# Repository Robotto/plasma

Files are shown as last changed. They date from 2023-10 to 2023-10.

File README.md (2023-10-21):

Interfacing a plasma VU meter from the past with an ESP8266 on a Wemos D1 mini board.

This is highly experimental, dangerous, and possibly fun.

[Interactive BOM here](https://htmlpreview.github.io/?https://github.com/robotto/plasma/blob/master/bom/ibom.html).

[OH! And check out KiCanvas!](https://kicanvas.org/?github=https%3A%2F%2Fgithub.com%2FRobotto%2Fplasma)

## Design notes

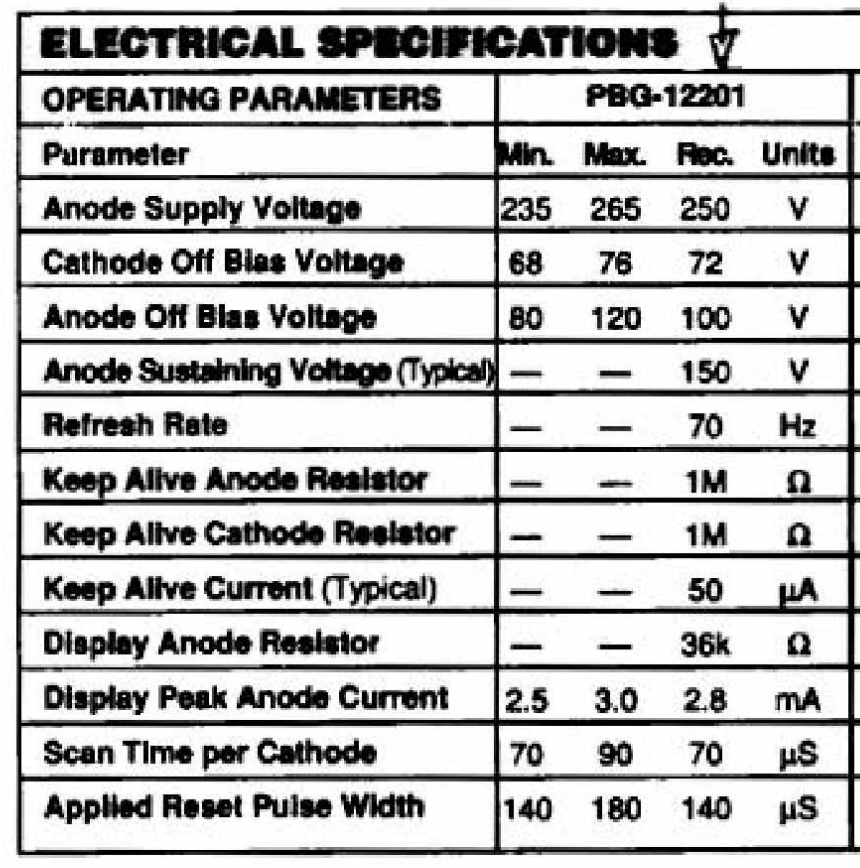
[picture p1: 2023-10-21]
electrical_specs.png

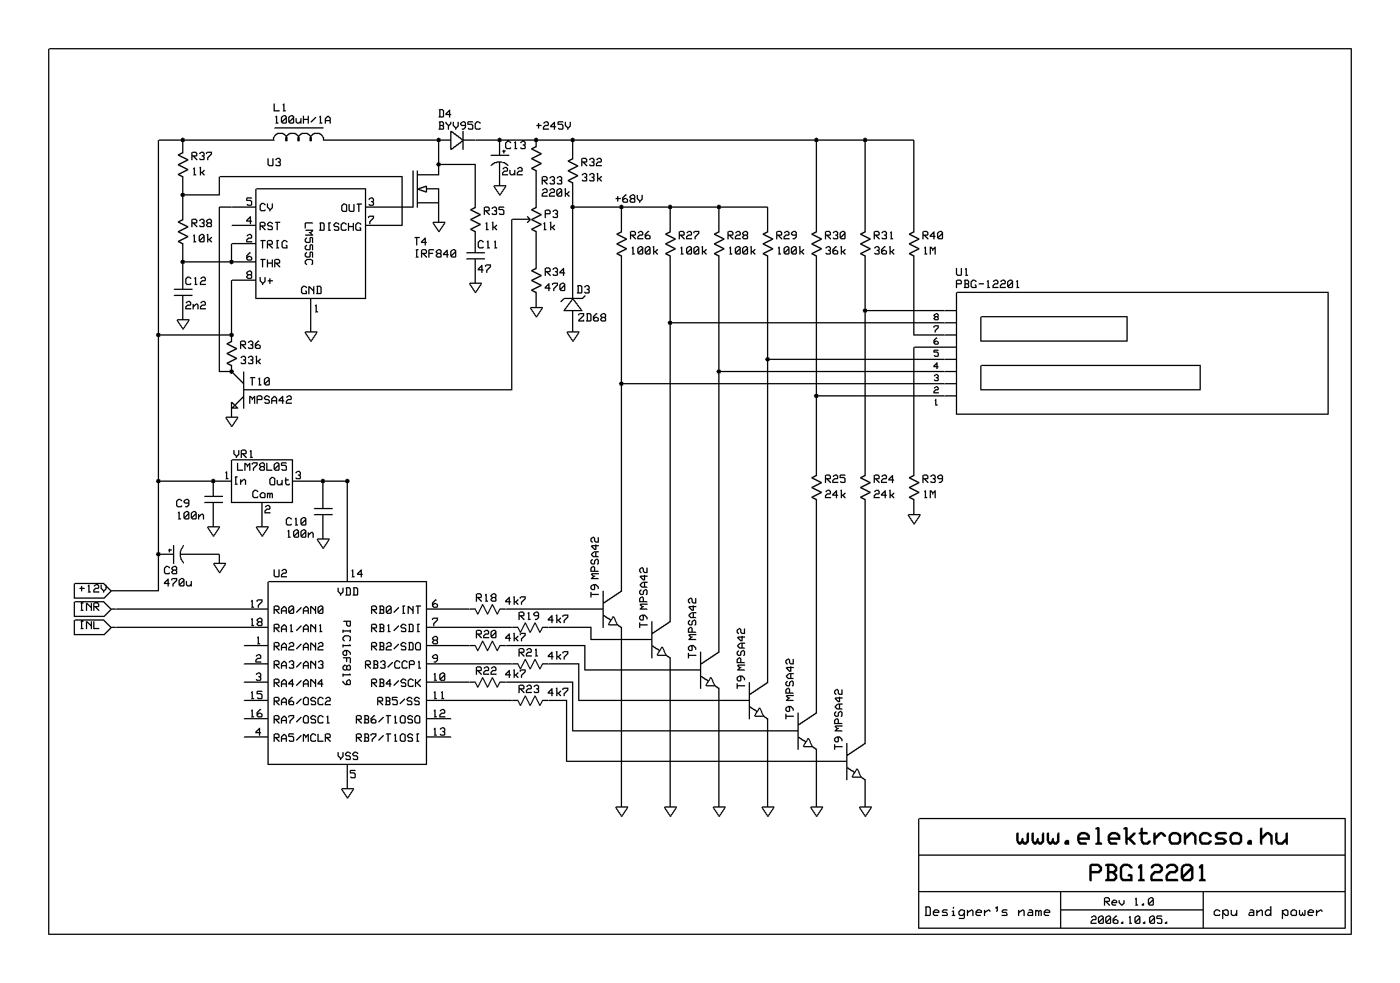
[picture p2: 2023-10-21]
plasma_VU_selfscan_kapcs.gif

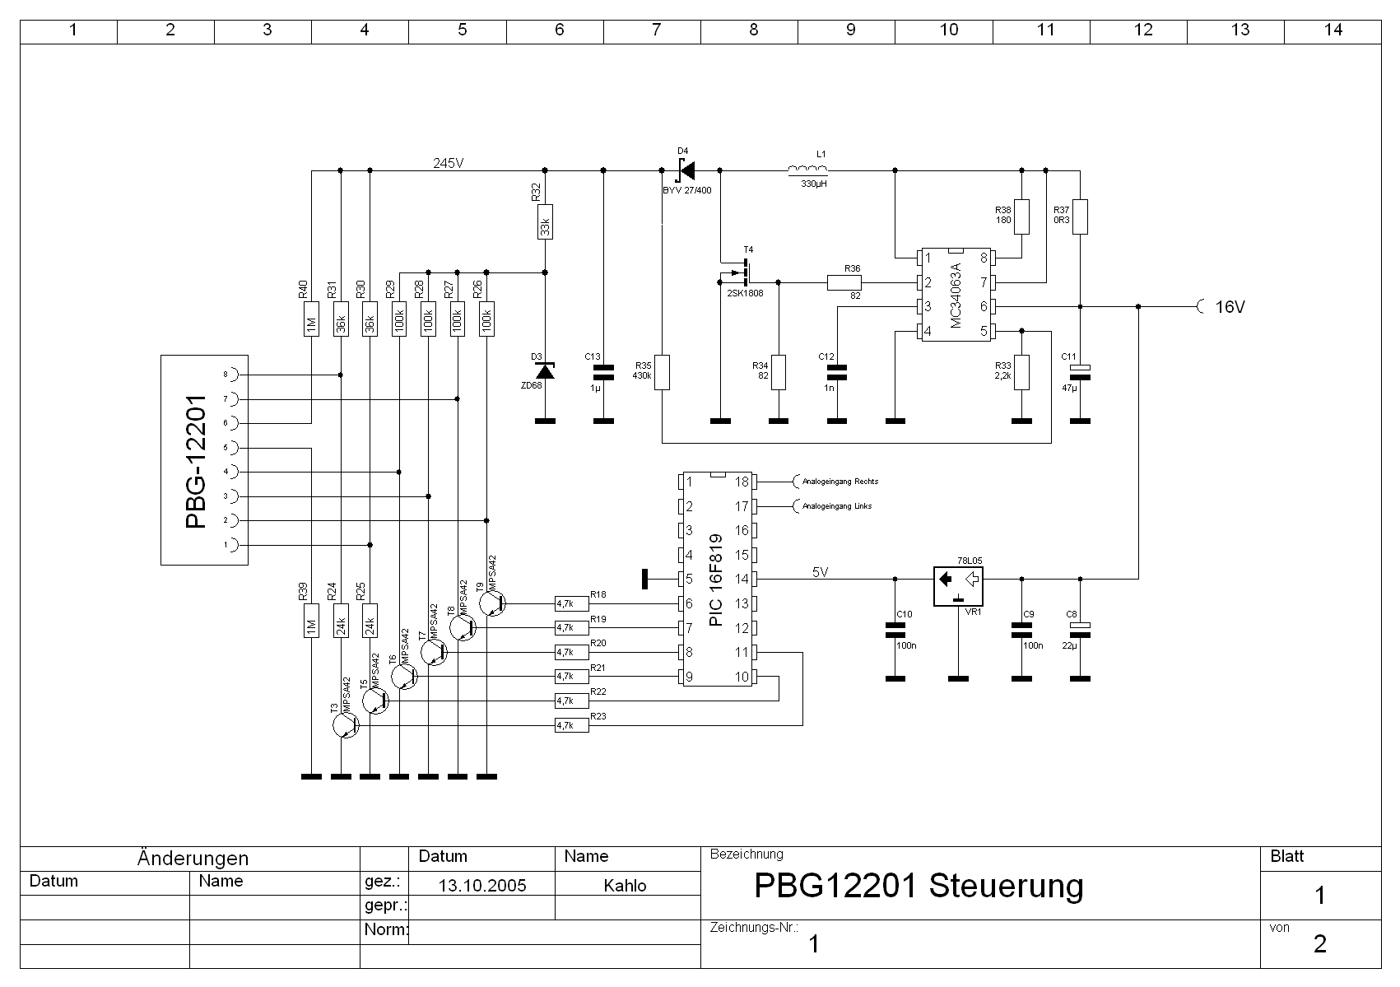
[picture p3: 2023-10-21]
Schaltplan_Teil1.gif

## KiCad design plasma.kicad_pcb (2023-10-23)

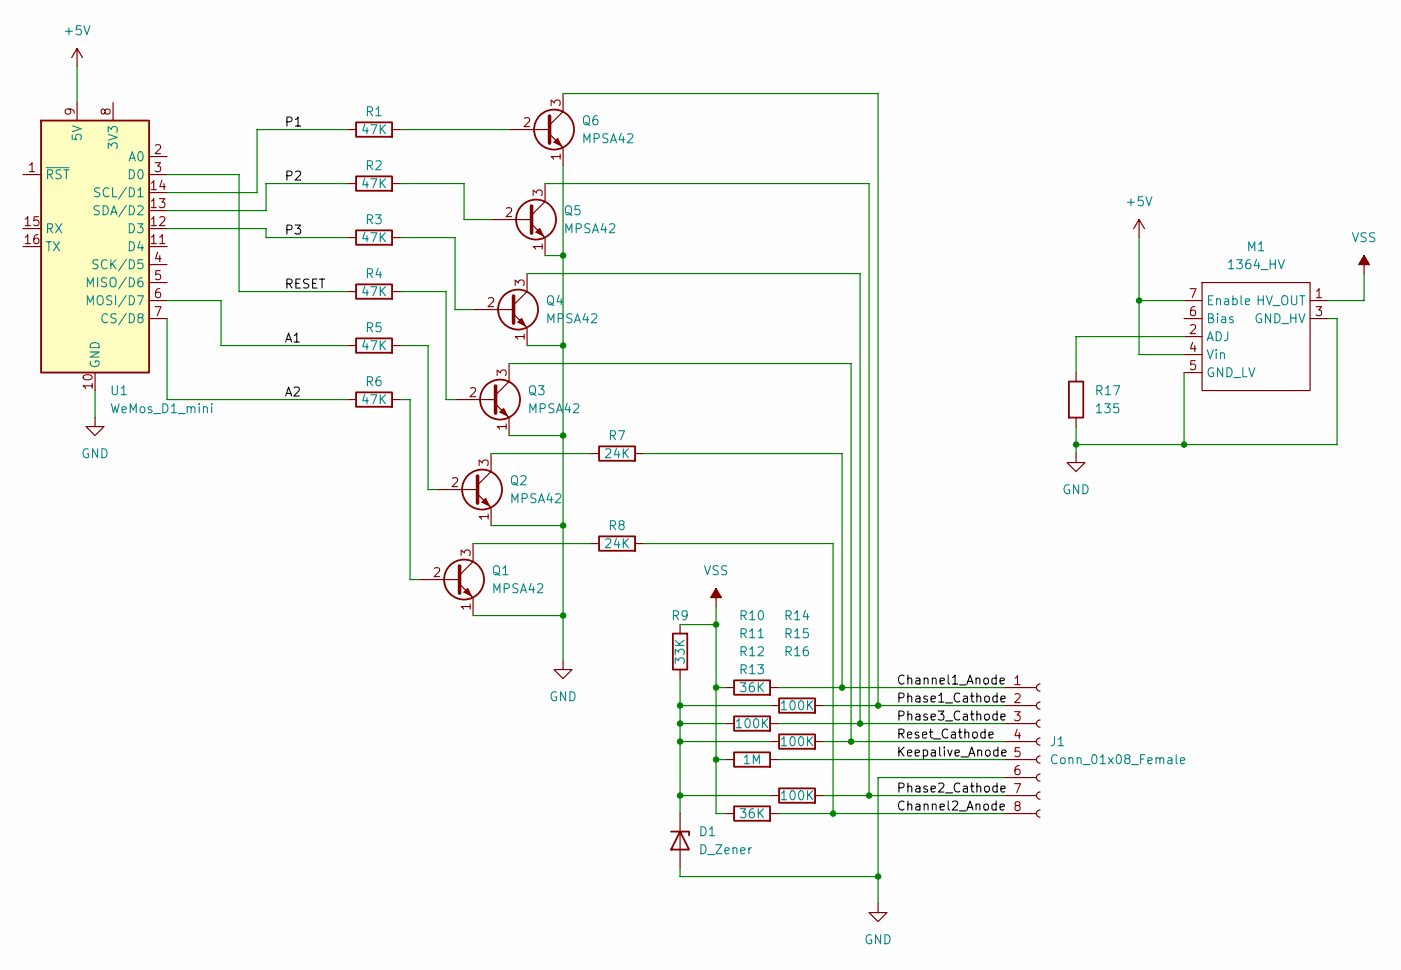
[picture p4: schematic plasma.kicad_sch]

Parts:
D1: D_Zener; R_Axial_DIN0207_L6.3mm_D2.5mm_P7.62mm_Horizontal
J1: Conn_01x08_Female; PinHeader_1x08_P2.54mm_Horizontal
M1: 1364_HV
Q1, Q2, Q3, Q4, Q5, Q6: MPSA42; TO-92_Inline
R1, R2, R3, R4, R5, R6: 47K; R_Axial_DIN0207_L6.3mm_D2.5mm_P7.62mm_Horizontal
R7, R8: 24K; R_Axial_DIN0207_L6.3mm_D2.5mm_P7.62mm_Horizontal
R9: 33K; R_Axial_DIN0207_L6.3mm_D2.5mm_P7.62mm_Horizontal
R10, R13: 36K; R_Axial_DIN0207_L6.3mm_D2.5mm_P7.62mm_Horizontal
R11, R14, R15, R16: 100K; R_Axial_DIN0207_L6.3mm_D2.5mm_P7.62mm_Horizontal
R12: 1M; R_Axial_DIN0207_L6.3mm_D2.5mm_P7.62mm_Horizontal
R17: 135; R_Axial_DIN0207_L6.3mm_D2.5mm_P7.62mm_Horizontal
U1: WeMos_D1_mini; WEMOS_D1_mini_light

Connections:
+5V: M1.4 (Vin), M1.7 (Enable), U1.9 (5V)
/A1: R5.1, U1.6 (MOSI/D7)
/A2: R6.1, U1.7 (CS/D8)
/Channel1_Anode: J1.1, R7.2, R10.2
/Channel2_Anode: J1.8, R8.2, R13.2
/Keepalive_Anode: J1.5, R12.2
/P1: R1.1, U1.14 (SCL/D1)
/P2: R2.1, U1.13 (SDA/D2)
/P3: R3.1, U1.12 (D3)
/Phase1_Cathode: J1.2, Q6.3 (C), R14.2
/Phase2_Cathode: J1.7, Q5.3 (C), R16.2
/Phase3_Cathode: J1.3, Q4.3 (C), R11.2
/RESET: R4.1, U1.3 (D0)
/Reset_Cathode: J1.4, Q3.3 (C), R15.2
GND: D1.2 (A), J1.6, M1.3 (GND_HV), M1.5 (GND_LV), Q1.1 (E), Q2.1 (E), Q3.1 (E), Q4.1 (E), Q5.1 (E), Q6.1 (E), R17.2, U1.10 (GND)
unnamed: D1.1 (K), R9.1, R11.1, R14.1, R15.1, R16.1
unnamed: M1.2 (ADJ), R17.1
unnamed: Q1.2 (B), R6.2
unnamed: Q1.3 (C), R8.1
unnamed: Q2.2 (B), R5.2
unnamed: Q2.3 (C), R7.1
unnamed: Q3.2 (B), R4.2
unnamed: Q4.2 (B), R3.2
unnamed: Q5.2 (B), R2.2
unnamed: Q6.2 (B), R1.2
VSS: M1.1 (HV_OUT), R9.2, R10.1, R12.1, R13.1

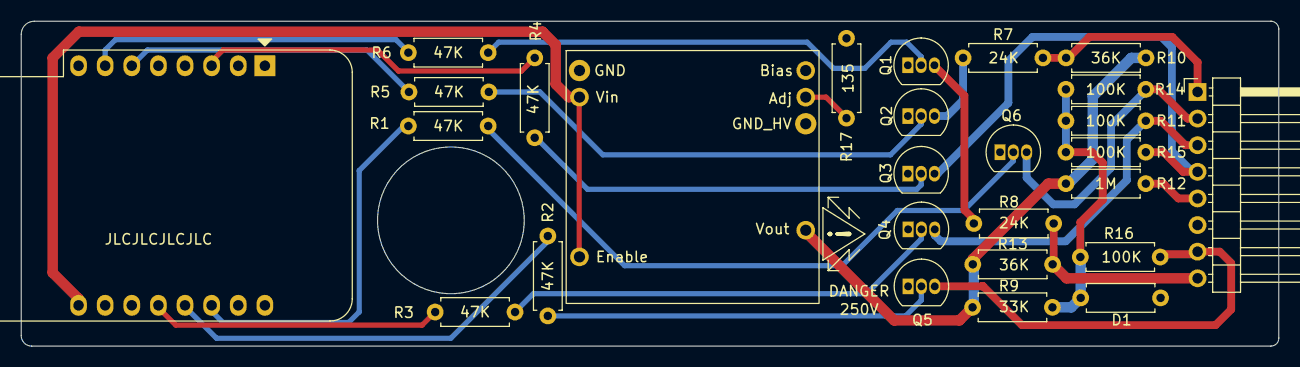
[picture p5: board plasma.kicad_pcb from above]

Board: 2 copper layers, 120.0 x 31.0 mm, 27 parts (0 on the bottom side), 26 nets.

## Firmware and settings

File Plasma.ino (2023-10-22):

int P1 = D1;
int P2 = D2;
int P3 = D3; //Also LED pin :/
int R  = D0;
int A1 = D7;
int A2 = D8;


#define ANODE_ON LOW
#define ANODE_OFF HIGH
#define CATHODE_ON HIGH
#define CATHODE_OFF LOW

void setup() {
  Serial.begin(115200);
  //all pins to output
  pinMode(P1, OUTPUT);
  pinMode(P2, OUTPUT);
  pinMode(P3, OUTPUT);
  pinMode(R,  OUTPUT);
  pinMode(A1, OUTPUT);
  pinMode(A2, OUTPUT);

  //all phase pins off
  digitalWrite(P1, CATHODE_OFF);
  digitalWrite(P2, CATHODE_OFF);
  digitalWrite(P3, CATHODE_OFF);
  digitalWrite(R,  CATHODE_OFF);

  //anodes on!
  digitalWrite(A1, ANODE_ON);
  digitalWrite(A2, ANODE_ON);
}

#define PHASOR_DELAY_MICROSECONDS 70
#define RESET_DELAY_MICROSECONDS 140

uint8_t segmentCounter = 0; //continuously runing from 0 to 199.
unsigned long nextPhaseAtMicros = 0;

int target_1=0;
int target_2=0;

 int frq=1;
 int offset = 100;
 int amplitude = 100;

void loop() {

  target_1 = (amplitude * sin(2 * PI * frq * micros() * 0.000001) + offset);
  target_2 = (amplitude * cos(2 * PI * frq * micros() * 0.000001) + offset);

  if ( micros() > nextPhaseAtMicros) phasor();
}
 
void phasor()
{
  if(segmentCounter==200){
      
      segmentCounter=2;

      //All phases to 0:
      digitalWrite(P1, CATHODE_OFF);
      digitalWrite(P2, CATHODE_OFF);
      digitalWrite(P3, CATHODE_OFF);

      //Pulse the reset pin:
      digitalWrite(R, CATHODE_ON);
      delayMicroseconds(PHASOR_DELAY_MICROSECONDS);

      digitalWrite(A1, ANODE_ON);
      digitalWrite(A2, ANODE_ON);
  }
//Every third count comes back to the same state.
else{
  digitalWrite(R, CATHODE_OFF);

  switch ( segmentCounter%3 ){ 
    case 0:
      digitalWrite(P1, CATHODE_ON );
      digitalWrite(P2, CATHODE_OFF);
      digitalWrite(P3, CATHODE_OFF);
      break;
    case 1:
      digitalWrite(P1, CATHODE_OFF);
      digitalWrite(P2, CATHODE_ON );
      digitalWrite(P3, CATHODE_OFF);
      break;
    case 2:
      digitalWrite(P1, CATHODE_OFF);
      digitalWrite(P2, CATHODE_OFF);
      digitalWrite(P3, CATHODE_ON );
      break;
    default: //should never happen, but here we go anyway... 
      break;
  }
  
  if( target_1 < segmentCounter) digitalWrite(A1, ANODE_OFF);
  if( target_2 < segmentCounter) digitalWrite(A2, ANODE_OFF);
}
  segmentCounter++;
  nextPhaseAtMicros = micros() + PHASOR_DELAY_MICROSECONDS;  
}

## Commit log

2023-03-09 git init
    [plasma.kicad_pcb, plasma.kicad_sch]
2023-03-09 playing the routing game
    [plasma.kicad_pcb]
2023-03-11 added plasma vu-meter dimensions. trying to match them to the board
    [plasma.kicad_pcb]
2023-03-13 moved the hole, made some gerbers
    [plasma-B_Cu.gbr, plasma-B_Mask.gbr, plasma-B_Paste.gbr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]
2023-03-14 rounded PCB corners
    [plasma.kicad_pcb]
2023-03-14 updated gerbers
    [plasma-B_Cu.gbr, plasma-B_Mask.gbr, plasma-B_Paste.gbr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]
2023-03-14 added interactive bom, generated by awesome plugin.
2023-10-20 Rework new timing to match hw pinout
    [Plasma.ino]
2023-10-21 Oh my god, my code was fine, except for wrong pinout :D
    [plasma-B_Cu.gbr, plasma-B_Mask.gbr, plasma-B_Paste.gbr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]
2023-10-22 Added fancy sine/cosine animations, and calibrated mininum and maximum values for the plasma to look AMAZING
2023-10-23 fine-tuning routing
    [plasma.kicad_pcb]
